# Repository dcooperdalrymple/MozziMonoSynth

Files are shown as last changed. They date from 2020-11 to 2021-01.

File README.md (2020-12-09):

# MozziMonoSynth
14-bit monophonic synthesizer using the [Mozzi sound synthesis library](https://github.com/sensorium/Mozzi). 3d-printable enclosure included!

#### Features Included:
- 16-bit digital signal processing internally
- 14-bit audio output using Mozzi HIFI mode
- Audio output buffering using MC14069UB hex inverter
- LM386 mono amplifier for headphones or internal speaker _(shutoff switch included for speaker)_
- Hardware Midi input using 6N138 optocoupler

<p float="left">
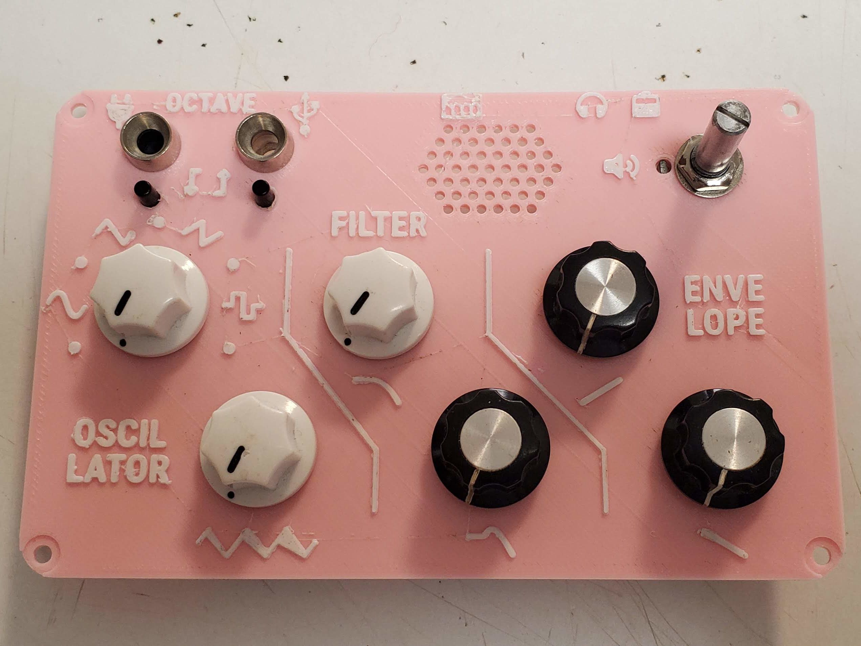
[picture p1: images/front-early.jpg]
Early version of faceplate
  
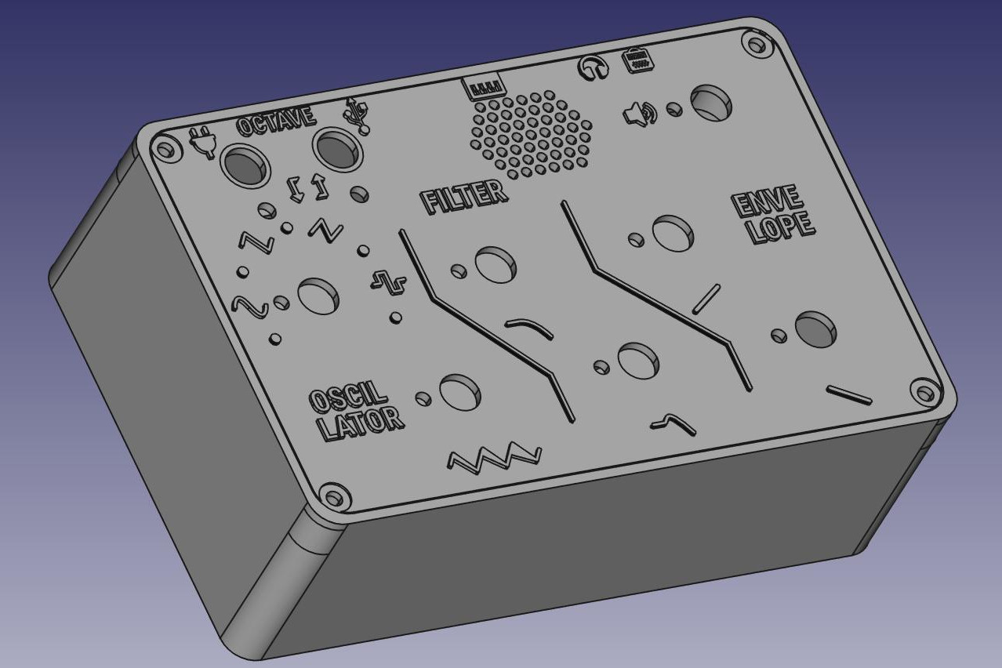
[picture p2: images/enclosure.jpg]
View of enclosure in FreeCAD
  
</p>

> Still in early development, but more details and schematics to come soon.

#### Control Mapping

| Knob | Mode 1 | Mode 2 (left) | Mode 3 (right) |
| :--: | --- | --- | --- |
| 1 | Oscillator 1 Waveform | Oscillator 2 Waveform | Oscillator Detune |
| 2 | LFO Amount | LFO Frequency | LFO Destination |
| 3 | Filter Frequency | Envelope Amount | Oscillator Mix |
| 4 | Filter Resonance | Envelope Level | Oscillator Tune |
| 5 | Amp Attack | Envelope Attack | Amp Decay |
| 6 | Amp Release | Envelope Release | Envelope Decay |

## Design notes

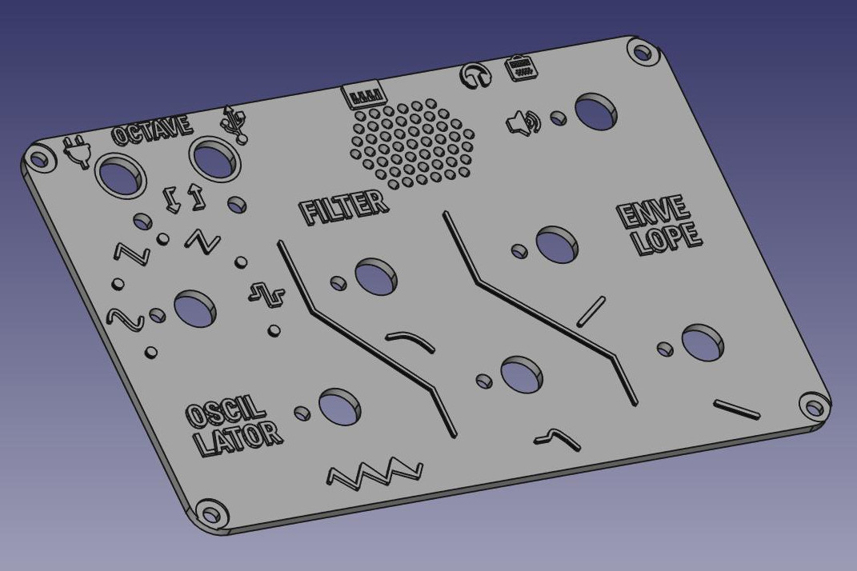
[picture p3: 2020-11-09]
images/enclosure-top.jpg

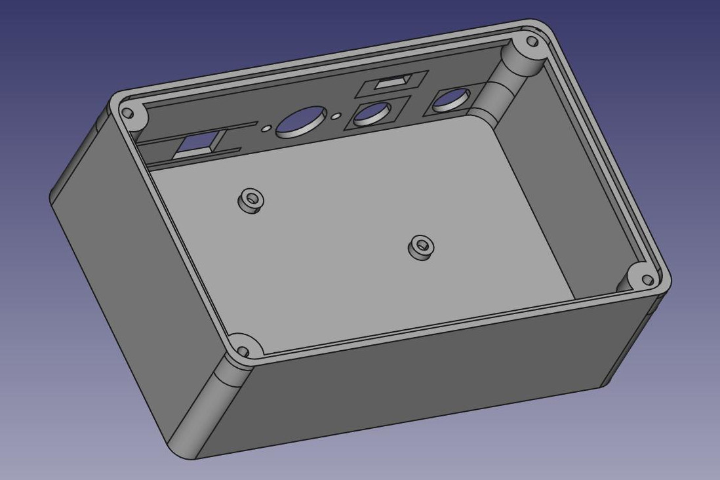
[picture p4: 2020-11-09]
images/enclosure-bottom.jpg

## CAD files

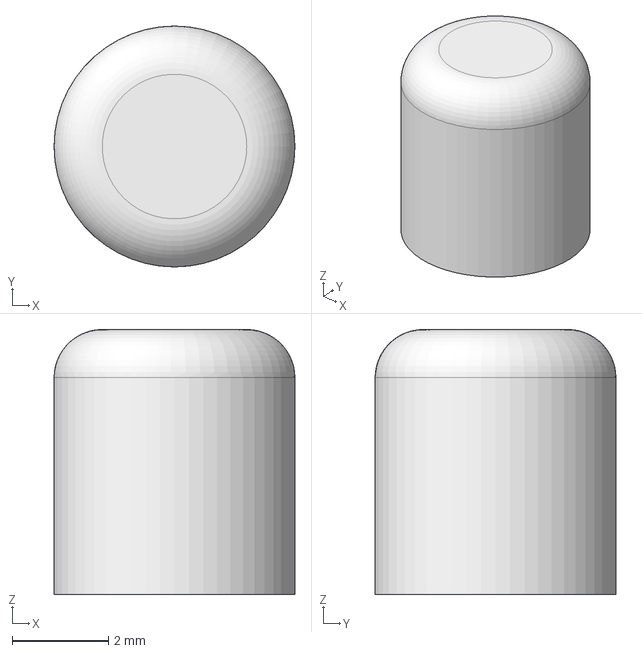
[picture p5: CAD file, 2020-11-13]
enclosure/ButtonCap.FCStd
5.00 x 5.00 x 5.50 mm

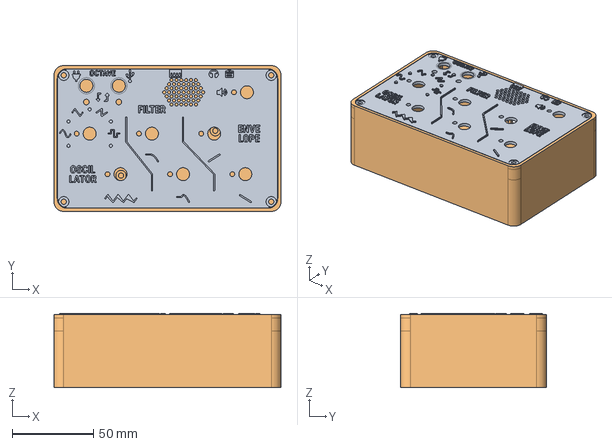
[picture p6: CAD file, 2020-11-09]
enclosure/MozziMonoSynth.FCStd
140.0 x 90.0 x 45.8 mm
Enclosure Top
Enclosure Bottom

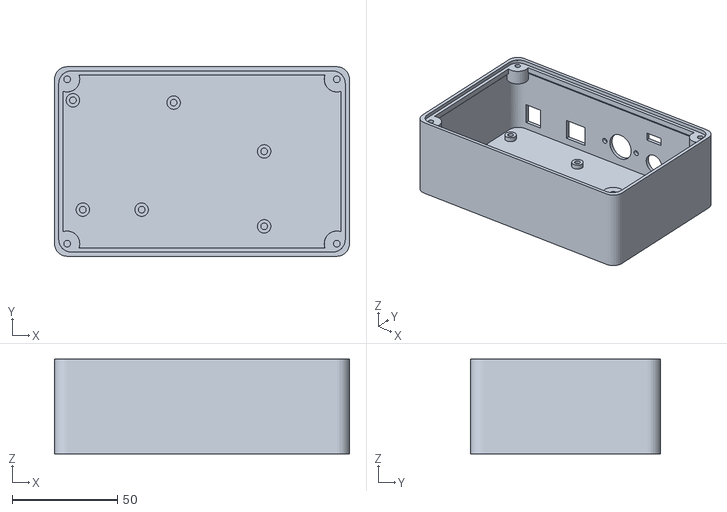
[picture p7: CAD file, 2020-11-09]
enclosure/MozziMonoSynth-Bottom.stl
140.0 x 90.0 x 45.0

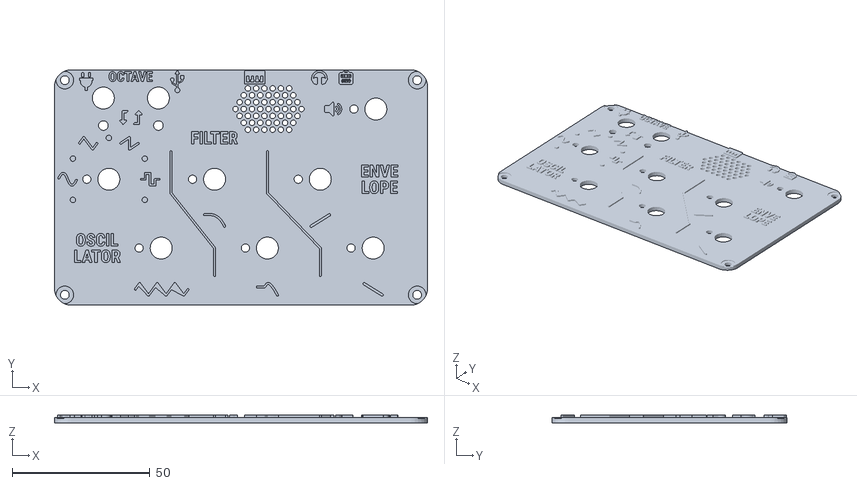
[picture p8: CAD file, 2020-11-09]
enclosure/MozziMonoSynth-Top.stl
135.5 x 85.5 x 2.75

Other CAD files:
enclosure/ButtonCap.stl

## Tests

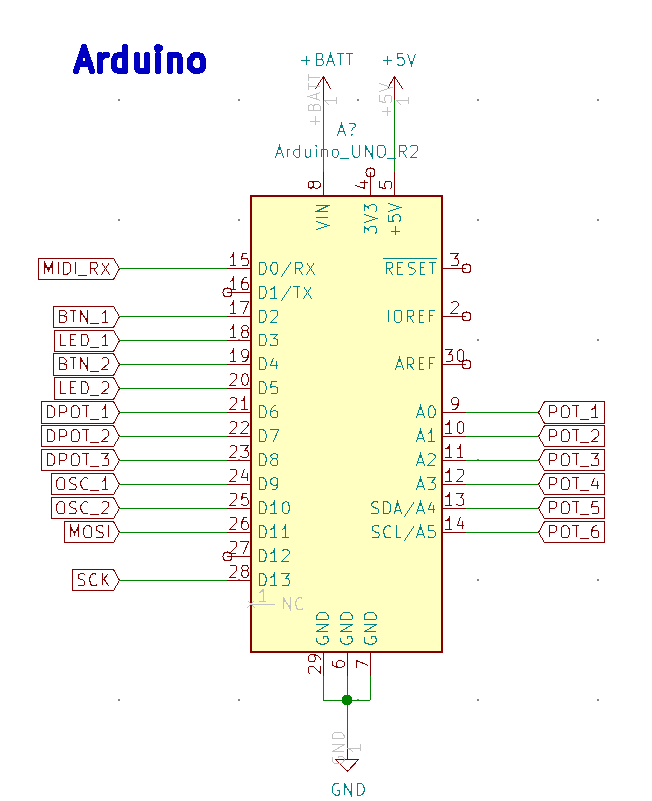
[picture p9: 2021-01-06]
tests/OscillatorTest/schem-arduino.png

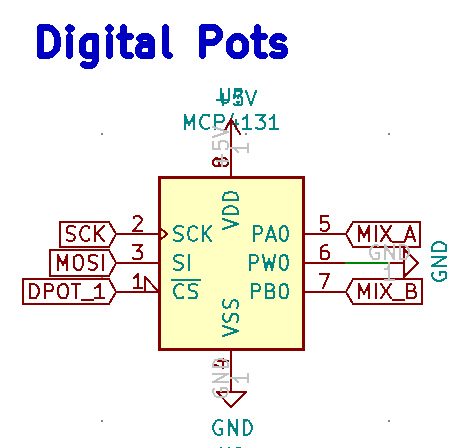
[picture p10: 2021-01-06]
tests/OscillatorTest/schem-digipot.png

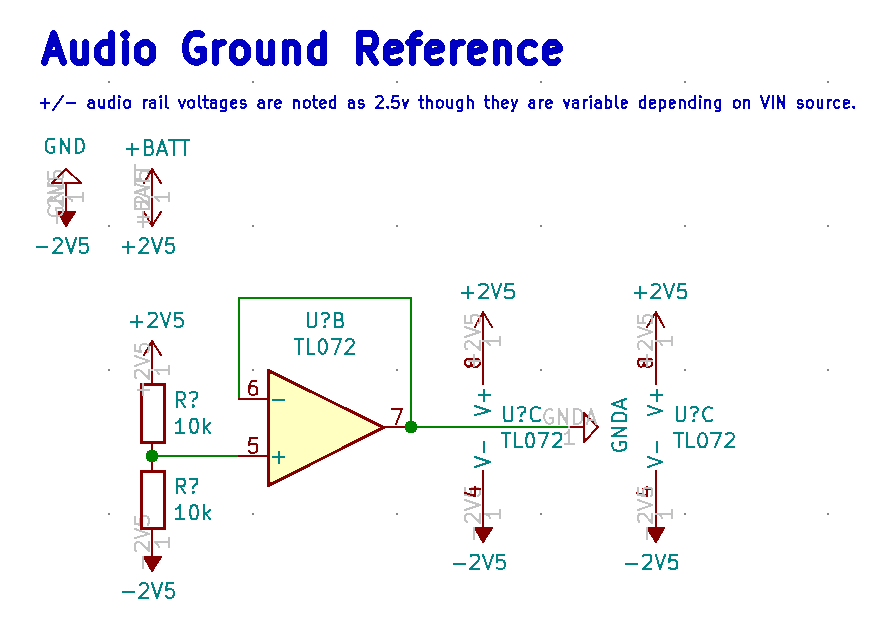
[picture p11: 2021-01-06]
tests/OscillatorTest/schem-agnd.png

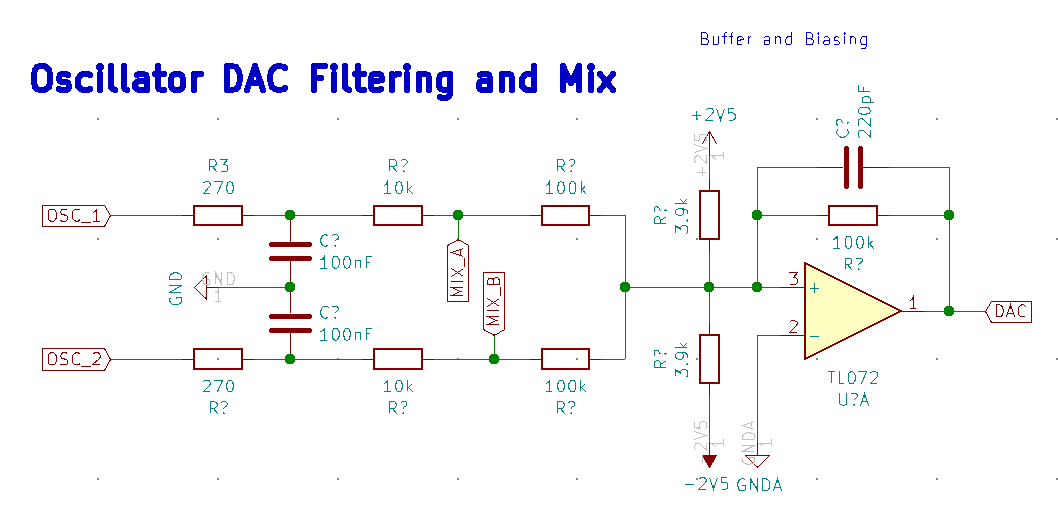
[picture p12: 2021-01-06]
tests/OscillatorTest/schem-oscmix.png

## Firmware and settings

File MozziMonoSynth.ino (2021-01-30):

/**
 * Title: MozziMonoSynth
 * Version: 0.1.0
 * Author: D Cooper Dalrymple
 * Created: 11/04/2020
 * Updated: 11/17/2020
 * Description: 14-bit monophonic synthesizer using the Mozzi audio synthesis library. Best used for bass voices. Uses HiFi mode on Arduino Uno with hex inverter buffer and hardware low pass filter.
 * https://dcooperdalrymple.com/
 */

// Global Constants
#include "Constants.h"
//#define SERIAL_DEBUG // Enable Debugging
#define CONTROL_RATE 64

// Libraries
#ifndef SERIAL_DEBUG
#include <MIDI.h>
MIDI_CREATE_DEFAULT_INSTANCE();
#endif

#include <MozziGuts.h>
#include <mozzi_fixmath.h>
#include <mozzi_midi.h>
#include <Line.h>

// Local Classes
#include "NoteBank.h"
#include "Controls.h"
#include "Voice.h"
#include "Program.h"

// Objects
NoteBank note_bank;
Voice voice;
Program program;

// Local Function Declarations
void loadProgramVoice(uint8_t index = 0);
void updateVoiceControls();

// Begin Setup

void setup() {

    pinMode(STATUS_LED, OUTPUT);
    digitalWrite(STATUS_LED, LOW);

    Controls::setup();
    Controls::setUpdateHandler(updateVoiceControl);
    Controls::setWriteProgramCallback(writeProgramVoice);
    Controls::setReadProgramCallback(loadProgramVoice);

    voice.init();

    //loadProgramVoice(0);

    startMozzi(CONTROL_RATE);

    #ifndef SERIAL_DEBUG
    MIDI.setHandleNoteOn(receiveNoteOn);
    MIDI.setHandleNoteOff(receiveNoteOff);
    MIDI.begin(MIDI_CHANNEL_OMNI);
    #else
    Serial.begin(9600);
    Serial.println("MozziMonoSynth v0.1.0 - D Cooper Dalrymple 2020");
    receiveNoteOn(0, 49, 255); // Play note if debugging
    #endif
}

void loop() {
    audioHook();
}

void updateControl() {

    #ifndef SERIAL_DEBUG
    // Flush Midi buffer
    while (MIDI.read()) { };
    #endif

    // Check for control updates and update voice with handler
    Controls::update();

    // Update control rate parameters of voice
    if (Controls::getState() != STATE_PROGRAM) voice.update();

    // LED display
    switch (Controls::getState()) {
        case STATE_PRIMARY:
            // Fade LED with LFO and Envelope
            Controls::setLed(LED_1_KEY, voice.getCurrentLFO());
            Controls::setLed(LED_2_KEY, voice.getCurrentGain());
            break;
        case STATE_SECONDARY:
            Controls::setLed(LED_1_KEY, LED_ON);
            Controls::setLed(LED_2_KEY, LED_OFF);
            break;
        case STATE_TERTIARY:
            Controls::setLed(LED_1_KEY, LED_OFF);
            Controls::setLed(LED_2_KEY, LED_ON);
            break;
        case STATE_PROGRAM:
            // Indicate the selected program
            uint8_t p = Controls::getSelectedProgram();
            Controls::setLed(LED_1_KEY, p & B10 ? LED_ON : LED_DIM);
            Controls::setLed(LED_2_KEY, p & B01 ? LED_ON : LED_DIM);
            break;
    }

}

int16_t updateAudio() {
    Controls::updateLeds();

    if (Controls::getState() == STATE_PROGRAM) {
        return 0; // Mute when reading/writing program
    } else {
        return voice.next();
    }
}

// Midi Callbacks

void receiveNoteOn(byte channel, byte note, byte velocity) {
    digitalWrite(STATUS_LED, HIGH);

    note_bank.removeNote(note); // Prevent duplicates
    note_bank.addNote(note);

    voice.noteOn(note_bank.getNote());
}

void receiveNoteOff(byte channel, byte note, byte velocity) {
    if (note_bank.removeNote(note) == false) return;
    if (note_bank.hasNote()) {
        voice.noteOn(note_bank.getNote());
    } else {
        digitalWrite(STATUS_LED, LOW);
        voice.noteOff();
    }
}

// Controls transfer to voice

void updateVoiceControl(uint8_t key, uint16_t value) {
    #ifdef SERIAL_DEBUG
    Serial.print("Control Change: ");
    Serial.print(key);
    Serial.print(", ");
    Serial.println(value);
    #endif

    switch (key) {

        case OSC_1_WAVEFORM_KEY:
            voice.setOscillatorWaveform(0, (uint8_t)value);
            break;
        case OSC_2_WAVEFORM_KEY:
            voice.setOscillatorWaveform(1, (uint8_t)value);
            break;
        case OSC_DETUNE_KEY:
            voice.setOscillatorDetune(value);
            break;
        case OSC_MIX_KEY:
            voice.setOscillatorMix((uint8_t)value);
            break;
        case OSC_TUNE_KEY:
            voice.setOscillatorTune(value);
            break;

        case LFO_AMOUNT_KEY:
            voice.setLfoAmount((uint8_t)value);
            break;
        case LFO_FREQUENCY_KEY:
            voice.setLfoFrequency(value);
            break;
        case LFO_DESTINATION_KEY:
            voice.setLfoDestination((uint8_t)value);
            break;

        case LPF_FREQUENCY_KEY:
            if (Controls::isUpdated(LPF_RESONANCE_KEY)) break;
        case LPF_RESONANCE_KEY:
            voice.setFilterFrequencyResonance((uint8_t)Controls::getPot(LPF_FREQUENCY_KEY), (uint8_t)Controls::getPot(LPF_RESONANCE_KEY));
            break;

        case ENV_1_ATTACK_KEY:
            if (Controls::isUpdated(ENV_1_DECAY_KEY)) break;
        case ENV_1_DECAY_KEY:
            if (Controls::isUpdated(ENV_1_RELEASE_KEY)) break;
        case ENV_1_RELEASE_KEY:
            voice.setEnvelopeTimes(0, Controls::getPot(ENV_1_ATTACK_KEY), Controls::getPot(ENV_1_RELEASE_KEY), Controls::getPot(ENV_1_DECAY_KEY));
            break;

        case ENV_2_AMOUNT_KEY:
            voice.setEnvelopeAmount(1, (uint8_t)value);
            break;
        case ENV_2_LEVEL_KEY:
            voice.setEnvelopeLevel(1, (uint8_t)value);
            break;
        case ENV_2_ATTACK_KEY:
            if (Controls::isUpdated(ENV_2_DECAY_KEY)) break;
        case ENV_2_RELEASE_KEY:
            if (Controls::isUpdated(ENV_2_RELEASE_KEY)) break;
        case ENV_2_DECAY_KEY:
            voice.setEnvelopeTimes(1, Controls::getPot(ENV_2_ATTACK_KEY), Controls::getPot(ENV_2_RELEASE_KEY), Controls::getPot(ENV_2_DECAY_KEY));
            break;

    }
}

// Program transfer to controls and voice

void writeProgramVoice(uint8_t index) {
    for (uint8_t i = 0; i < CONTROLS_NUM_POTS; i++) {
        program.set(i, Controls::getPot(i, false));
    }
    program.write(index);
}
void loadProgramVoice(uint8_t index) {
    program.read(index);
    for (uint8_t i = 0; i < CONTROLS_NUM_POTS; i++) {
        Controls::setPot(i, program.get(i), true);
        updateVoiceControl(i, program.get(i));
    }
}

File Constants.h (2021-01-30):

/*
 * Constants.h
 * Version: 0.1.1
 * Since: 0.1.1
 */

#ifndef CONSTANTS_H_
#define CONSTANTS_H_

#define STATUS_LED 13

/*************
 * Voice     *
 *************/

// Oscillator
#define OSC_NUM_CELLS SIN1024_NUM_CELLS
#define OSC_WAVEFORM_NUM 4
#define OSC_MIX_MIN 0
#define OSC_MIX_MAX 255
#define OSC_MIX_MID (OSC_MIX_MAX + OSC_MIX_MIN) / 2
const float oscTuneMin = 0.5f;
const float oscTuneMax = 2.f;
const float oscDetuneMin = 0.0f;
const float oscDetuneMax = 0.1f;

// LFO
#define LFO_AMOUNT_GAP 20
#define LFO_AMOUNT_MIN 0
#define LFO_AMOUNT_MAX 255
const float lfoFrequencyMin = 0.5f;
const float lfoFrequencyMax = 20.f;
#define LFO_NUM_CELLS SIN1024_NUM_CELLS

#define LFO_DESTINATION_MIN 0
#define LFO_DESTINATION_MAX 4
#define LFO_DESTINATION_OSC_TUNE 0
#define LFO_DESTINATION_OSC_MIX 1
#define LFO_DESTINATION_LPF_FREQ 2
#define LFO_DESTINATION_LPF_RESO 3

// Low Pass Filter
#define LPF_FREQUENCY_MIN 20
#define LPF_FREQUENCY_MAX 255
#define LPF_RESONANCE_MIN 0
#define LPF_RESONANCE_MAX 220

// Envelope
#define ENV_AMOUNT_MIN 0
#define ENV_AMOUNT_MAX 255
#define ENV_ATTACK_LEVEL 255
#define ENV_DECAY_LEVEL_MIN 0
#define ENV_DECAY_LEVEL_MAX 255
#define ENV_DECAY_LEVEL 255
#define ENV_DECAY_TIME 50
#define ENV_DECAY_MIN 20
#define ENV_DECAY_MAX 1000
#define ENV_SUSTAIN_TIME 60000
#define ENV_ATTACK_MIN 20
#define ENV_ATTACK_MAX 2000
#define ENV_RELEASE_MIN 20
#define ENV_RELEASE_MAX 4000

/*************
 * Note Bank *
 *************/

#define NOTE_BANK_SIZE 32

/*************
 * Controls  *
 *************/

#define STATE_PRIMARY 0
#define STATE_SECONDARY 1
#define STATE_TERTIARY 2
#define STATE_PROGRAM 3
#define STATE_NUM_POTS 6

#define CONTROLS_NUM_LEDS 2
#define CONTROLS_NUM_BUTTONS 2
#define CONTROLS_NUM_STATES 3 // Not including program state
#define CONTROLS_NUM_POTS STATE_NUM_POTS*CONTROLS_NUM_STATES

#define BUTTON_1_KEY 0
#define BUTTON_1_PIN 12
#define BUTTON_2_KEY 1
#define BUTTON_2_PIN 8

#define LED_1_KEY 0
#define LED_1_PIN 11
#define LED_2_KEY 1
#define LED_2_PIN 6

#define POT_1_PIN A5
#define POT_2_PIN A4
#define POT_3_PIN A3
#define POT_4_PIN A2
#define POT_5_PIN A1
#define POT_6_PIN A0

// Primary Pots

#define OSC_1_WAVEFORM_KEY 0
#define OSC_1_WAVEFORM_PIN POT_1_PIN
#define OSC_1_WAVEFORM_STATE STATE_PRIMARY

#define LFO_AMOUNT_KEY 1
#define LFO_AMOUNT_PIN POT_2_PIN
#define LFO_AMOUNT_STATE STATE_PRIMARY

#define LPF_FREQUENCY_KEY 2
#define LPF_FREQUENCY_PIN POT_3_PIN
#define LPF_FREQUENCY_STATE STATE_PRIMARY

#define LPF_RESONANCE_KEY 3
#define LPF_RESONANCE_PIN POT_4_PIN
#define LPF_RESONANCE_STATE STATE_PRIMARY

#define ENV_1_ATTACK_KEY 4
#define ENV_1_ATTACK_PIN POT_5_PIN
#define ENV_1_ATTACK_STATE STATE_PRIMARY

#define ENV_1_RELEASE_KEY 5
#define ENV_1_RELEASE_PIN POT_6_PIN
#define ENV_1_RELEASE_STATE STATE_PRIMARY

// Secondary Knobs

#define OSC_2_WAVEFORM_KEY 6
#define OSC_2_WAVEFORM_PIN POT_1_PIN
#define OSC_2_WAVEFORM_STATE STATE_SECONDARY

#define LFO_FREQUENCY_KEY 7
#define LFO_FREQUENCY_PIN POT_2_PIN
#define LFO_FREQUENCY_STATE STATE_SECONDARY

#define ENV_2_AMOUNT_KEY 8
#define ENV_2_AMOUNT_PIN POT_3_PIN
#define ENV_2_AMOUNT_STATE STATE_SECONDARY

#define ENV_2_LEVEL_KEY 9
#define ENV_2_LEVEL_PIN POT_4_PIN
#define ENV_2_LEVEL_STATE STATE_SECONDARY

#define ENV_2_ATTACK_KEY 10
#define ENV_2_ATTACK_PIN POT_5_PIN
#define ENV_2_ATTACK_STATE STATE_SECONDARY

#define ENV_2_RELEASE_KEY 11
#define ENV_2_RELEASE_PIN POT_6_PIN
#define ENV_2_RELEASE_STATE STATE_SECONDARY

// Tertiary Knobs

#define OSC_DETUNE_KEY 12
#define OSC_DETUNE_PIN POT_1_PIN
#define OSC_DETUNE_STATE STATE_TERTIARY

#define LFO_DESTINATION_KEY 13
#define LFO_DESTINATION_PIN POT_2_PIN
#define LFO_DESTINATION_STATE STATE_TERTIARY

#define OSC_MIX_KEY 14
#define OSC_MIX_PIN POT_3_PIN
#define OSC_MIX_STATE STATE_TERTIARY

#define OSC_TUNE_KEY 15
#define OSC_TUNE_PIN POT_4_PIN
#define OSC_TUNE_STATE STATE_TERTIARY

#define ENV_1_DECAY_KEY 16
#define ENV_1_DECAY_PIN POT_5_PIN
#define ENV_1_DECAY_STATE STATE_TERTIARY

#define ENV_2_DECAY_KEY 17
#define ENV_2_DECAY_PIN POT_6_PIN
#define ENV_2_DECAY_STATE STATE_TERTIARY

/*************
 * Program   *
 *************/

#define PROGRAM_COUNT 4
#define PROGRAM_DATA_SIZE (CONTROLS_NUM_POTS*2)

#endif /* CONSTANTS_H_ */

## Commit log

2020-11-09 Early arduino code and enclosure model.
    [MozziMonoSynth-Bottom.stl, MozziMonoSynth-Top.stl, MozziMonoSynth.FCStd]
2020-11-11 Simple arduino hardware tests.
2020-11-11 Simplified Midi test and added LED fading to Controls test.
2020-11-13 Added button cap model to fit long momentary pushbutton shaft.
    [ButtonCap.FCStd, ButtonCap.stl]
2020-11-13 Mostly working prototype, but room for improvement.
2020-11-14 Beginning work on Button controls, pot states, and program writing/loading. There are errors in this update that have yet to be resolved.
    [Button.h, Led.h, MozziMonoSynth.ino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]
2020-12-09 State bug fixes and voice improvements.
    [Button.h, Constants.h, Led.h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]
2021-01-06 Dual Oscillator SPI digital pot mix test complete. Sounds good! Schematic needs simplification.
    [OscillatorTest.ino]
